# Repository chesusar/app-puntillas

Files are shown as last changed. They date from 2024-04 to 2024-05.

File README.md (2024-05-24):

<div align="Center">
  <h1>Dispositivo IoT de Monitoreo de Equilibrio y Movimiento</h1>
  <p float="left">
    
    
  </p>
</div>

## Descripción
Este proyecto consiste en un dispositivo IoT diseñado para monitorear y analizar el equilibrio y los movimientos relacionados con mantenerse de puntillas. Utiliza un sensor IMU (Unidad de Medición Inercial) y un microcontrolador con Bluetooth para calcular diversas caracteristicas y enviar los datos a una aplicación de PC.

## Características
- **Tiempo hasta el ángulo máximo:** Mide el tiempo que se tarda en alcanzar el ángulo máximo al ponerse de puntillas desde el inicio del movimiento.
- **Tiempo de permanencia en puntillas:** Registra el tiempo durante el cual una persona puede mantenerse de puntillas.
- **Ángulo máximo alcanzado:** Mide el ángulo máximo logrado al estar de puntillas.
- **Ángulo mínimo en puntillas:** Determina el ángulo mínimo mientras se mantiene la posición de puntillas.
- **Promedio del ángulo en puntillas:** Calcula el promedio del ángulo durante la permanencia en puntillas.

## Componentes del Proyecto
- **Hardware del dispositivo IoT:**
  - Sensor IMU
  - Convertidor DC-DC
  - Microcontrolador con Bluetooth
  - Batería y componentes de montaje
- **Software:**
  - Código para el microcontrolador del dispositivo IoT
  - Código para el microcontrolador del recceptor
  - Aplicación para PC

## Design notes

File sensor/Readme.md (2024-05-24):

<div align="Center">
  <h1 align="Center">Dispositivo IoT de Monitoreo de Equilibrio y Movimiento - Sensor</h1>
  <p float="left">
    
  </p>
</div>

## Descripción
Este proyecto utiliza un dispositivo IoT basado en el sensor IMU para monitorear y analizar el equilibrio y los movimientos relacionados con mantenerse de puntillas. El dispositivo emplea un Arduino Nano 33 BLE Sense para procesar los datos del acelerómetro y el giroscopio, aplicando un filtro de Kalman para mejorar la precisión de las mediciones.

## Estructura de Carpetas
- codigo
  - dispositivo_iot.ino

- componentes
  - comparacion_IMUs.pdf
  - comparacion_DCDC.pdf
  - decisiones.pdf

- medidas
  - Datos_arduino
  - Datos_finales
  - Manejo_datos
    - convertir_datos.py
    - representar_datos.m

- modelo_3D
   - carcasa.stl

## Código
### Ubicación
El código fuente del dispositivo IoT se encuentra en la carpeta `codigo`.

### Descripción
El código está desarrollado para el **Arduino Nano 33 BLE Sense** y se encarga de:
- Tomar mediciones del acelerómetro y el giroscopio.
- Aplicar un filtro de Kalman para calcular el ángulo con mayor precisión.
- Enviar los datos procesados vía Bluetooth al receptor bluetooh del PC.

### Filtro de Kalman
El filtro de Kalman se utiliza para combinar las lecturas del acelerómetro y el giroscopio, proporcionando estimaciones más precisas del ángulo, reduciendo el ruido y mejorando la estabilidad de las mediciones.

<center>
  <video src="https://github.com/chesusar/app-puntillas/assets/133507131/c614b8c2-d482-485f-80f9-662d0921a47c" width="226" height="416"/> 
</center>

## Componentes
### Ubicación
La información sobre los componentes se encuentra en la carpeta `componentes`.

### Descripción
- **Sensor inercial.xlsx:** Comparación de diferentes sensores IMU considerados para el proyecto.
- **Reguladores de tensión.xlsx:** Comparación de diferentes convertidores DC-DC utilizados.
- **Comparacion_componentes.pdf:** Documento explicando las decisiones tomadas en la selección de componentes.

## Medidas
### Ubicación
Los datos de las mediciones se encuentran en la carpeta `medidas`.

### Descripción
- **Datos_arduino:** Lecturas de acelerómetro y giroscopio realizadas con el dispositivo IoT en diferentes personas.
- **Datos_finales:** Datos procesados a partir de las lecturas originales, separados en archivos CSV y un archivo Excel con información resumida de cada persona.
- **Manejo_datos:** Scripts para manejar y representar los datos:
  - `convertir_datos.py:` Script en Python para convertir los datos de `Datos_arduino` en `Datos_finales`.
  - `representar_datos.m:` Script en Matlab para representar los datos en gráficos.

## Modelo 3D
### Ubicación
El diseño de la carcasa para el dispositivo se encuentra en la carpeta `modelo_3D`.

### Descripción
- **Tobillera.stl:** Modelo 3D de la carcasa diseñada para integrar la batería y el sensor en un solo dispositivo compacto.

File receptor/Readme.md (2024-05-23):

<div align="Center">
  <h1 align="Center">Receptor Bluetooth con ESP32</h1>
  
</div>

Este proyecto utiliza un ESP32 como receptor Bluetooth para recibir datos de un dispositivo IoT basado en Arduino Nano 33 BLE Sense. El código principal se encuentra en `receptor.ino`.

## Descripción

El código realiza las siguientes tareas:

- Inicializa el módulo Bluetooth del ESP32.
- Publicita el ESP32 como un dispositivo Bluetooth accesible.
- Escanea y se conecta al dispositivo IoT específico.
- Suscribe las características relevantes del servicio Bluetooth.
- Lee y muestra los datos recibidos del dispositivo IoT, tales como ángulos y tiempos.

## Características BLE

El código se conecta a un servicio Bluetooth específico y se suscribe a las siguientes características:

- **UUID_PROCESAR:** Característica para iniciar o detener el procesamiento de datos.
- **UUID_MAX_ANGULO:** Característica que transmite el ángulo máximo medido.
- **UUID_MIN_ANGULO:** Característica que transmite el ángulo mínimo medido.
- **UUID_ANGULO:** Característica que transmite el ángulo actual.
- **UUID_ESTADO:** Característica que transmite el estado actual del dispositivo.
- **UUID_TIEMPO_SUBIDA:** Característica que transmite el tiempo de subida.
- **UUID_TIEMPO_ALTO:** Característica que transmite el tiempo mantenido en la posición elevada.
- **UUID_PROMEDIO:** Característica que transmite el ángulo promedio.

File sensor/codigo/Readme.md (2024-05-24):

<div align="Center">
  <h1 align="Center">Codigo del dispositivo IoT</h1>
  
</div>

## Descripción
Este código realiza las siguientes tareas:

- Inicializa los sensores del Arduino Nano 33 BLE Sense.
- Lee los datos del acelerómetro y el giroscopio.
- Aplica un filtro de Kalman para calcular el ángulo con precisión.
- Monitorea el estado del equilibrio y el movimiento.
- Envía los datos calculados a través de Bluetooth a una aplicación móvil o PC.

## Filtro de Kalman
El filtro de Kalman se utiliza para fusionar las lecturas del acelerómetro y el giroscopio, proporcionando estimaciones más precisas del ángulo y reduciendo el ruido en las mediciones.

<center>
  <h1>Dispositivo IoT de Monitoreo de Equilibrio y Movimiento</h1>
  
  <video src="https://github.com/chesusar/app-puntillas/assets/133507131/c614b8c2-d482-485f-80f9-662d0921a47c" width="226" height="416"/> 
</center>

## Maquina de estados
<div align="Center">
  <p float="left">
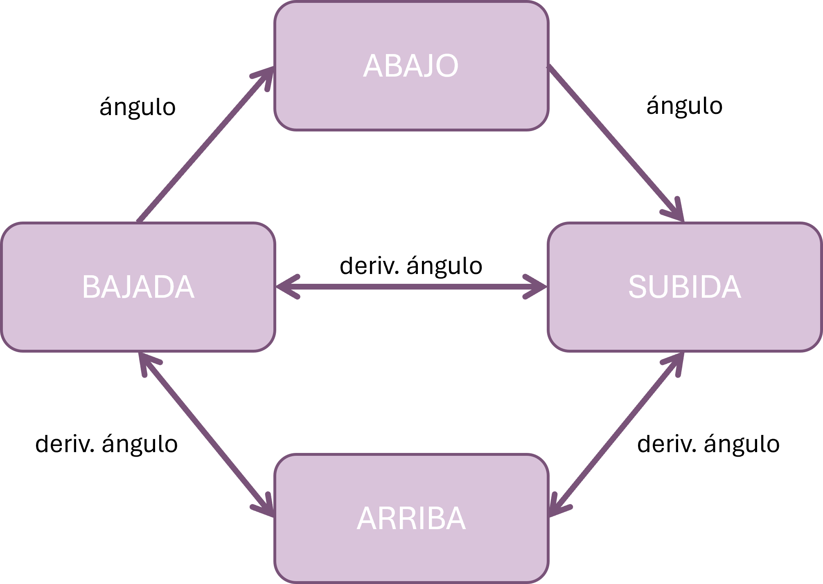
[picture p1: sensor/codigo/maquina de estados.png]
    
  </p>
</div>

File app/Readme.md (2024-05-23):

<div align="Center">
  <h1 align="Center">Na Punta Dos Pes APP</h1>
  <p float="left">
      
    
  </p>
</div>

## Descripción

Esta aplicación en Python se utiliza para interactuar con un dispositivo IoT que envía datos a través de Bluetooth Low Energy (BLE). El código principal se encuentra en `app.py`. La aplicación realiza las siguientes tareas:

- Se conecta al dispositivo IoT a través del receptor BLE.
- Suscribe las características relevantes del servicio BLE.
- Muestra los datos recibidos en una interfaz gráfica de usuario (GUI).
- Almacena los datos recibidos en el servidor de adafruit-io mediante peticiones MQTT.
- Permite iniciar y detener la transmisión de datos desde el dispositivo IoT.

## Datos recibidos y almacenados
- **Tiempo hasta el ángulo máximo:** Mide el tiempo que se tarda en alcanzar el ángulo máximo al ponerse de puntillas desde el inicio del movimiento.
- **Tiempo de permanencia en puntillas:** Registra el tiempo durante el cual una persona puede mantenerse de puntillas.
- **Ángulo máximo alcanzado:** Mide el ángulo máximo logrado al estar de puntillas.
- **Ángulo mínimo en puntillas:** Determina el ángulo mínimo mientras se mantiene la posición de puntillas.
- **Promedio del ángulo en puntillas:** Calcula el promedio del ángulo durante la permanencia en puntillas.

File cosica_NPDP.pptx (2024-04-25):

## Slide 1

Na ponta dos pés
(NPDP)
Sensor IoT puntillas

El proyecto se basa en desarrollar un dispositivo IoT que monitorea el equilibrio y los movimientos de puntillas. El dispositivo integra un sensor IMU y un microcontrolador con Bluetooth, colocándose en el pie derecho de una persona. El objetivo es calcular y registrar el tiempo para alcanzar el ángulo máximo al ponerse de puntillas, el tiempo que permanece en puntillas, el ángulo máximo alcanzado, el ángulo mínimo durante la permanencia en puntillas y el promedio del ángulo mientras se está de puntillas. Este enfoque ofrece aplicaciones potenciales en rehabilitación física, rendimiento deportivo y evaluación biomecánica.

(Arribas R. y Álvarez J., 2024)

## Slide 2

Mapa redondo simplificado e iconos

REAL - MUNDO VIRTUAL INTERFAZ
Interfaz de usuario (App)

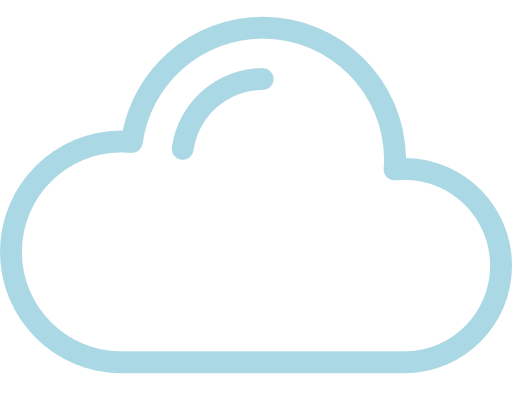
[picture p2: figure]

NUBE

ENTRADAS

Medidas

ENTRADA MANUAL

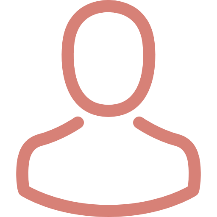
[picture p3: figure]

DEPORTE

SALUD

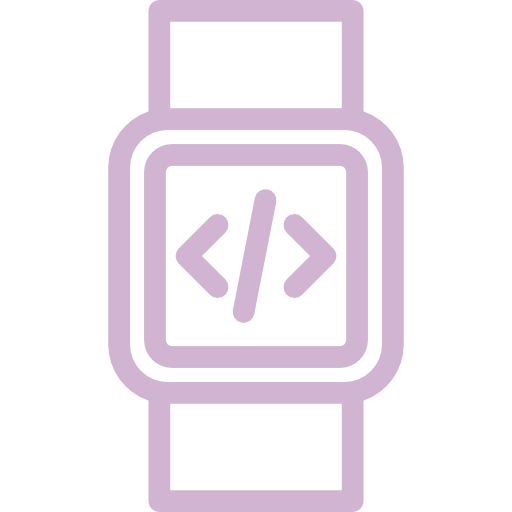
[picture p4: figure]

ENTRADA DE SENSOR

Inicio
Reset

MEDIDAS

Acelerómetro
Giróscopo

ORDENES
Al NPDP

NPDP

Wearable
Medida movimiento

SALIDAS

ENTRADA A LA NUBE

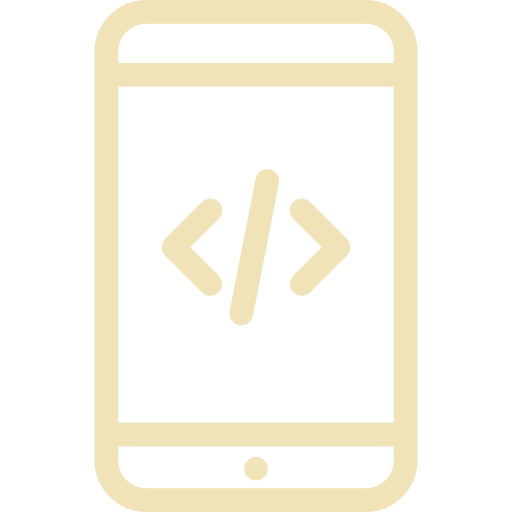
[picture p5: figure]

APP

INTERFAZ DE SALIDA

PC Configuración Visualization

SALIDA DE LA NUBE

APP – NPDP INTERFAZ
Bluetooth

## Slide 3

Entrada de información de los componentes e información generada

Información del mundo | | NPDP | APP | NUBE
Mundo real: Usuario | Medidas de movimiento
| Orden de inicio y de reset
Mundo real: contexto
Mundo virtual

INFORMACIÓN DEDUCIDA | NPDP | APP | NUBE
Tiempo de subida
Tiempo de puntillas
Ángulos

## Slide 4

Razonamiento de lsistema y salida de información generada

RAZONAMIENTO A PARTIR DE INFORMACIÓN COMPARTIDA | TOMA DE DECISIONES AL MUNDO | NPDP | APP | NUBE
Se mide y se notifica al usuario a través de la APP el estado en el que se encuentra, el tiempo que tarda en subir, el tiempo que esta de puntillas, el ángulo máximo, el ángulo mínimo estando de puntillas y el Angulo promedio estando de puntillas
| Notificación al usuario
| Orden de inicio

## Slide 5

Diseño en bloques del dispositivo (NPDP)

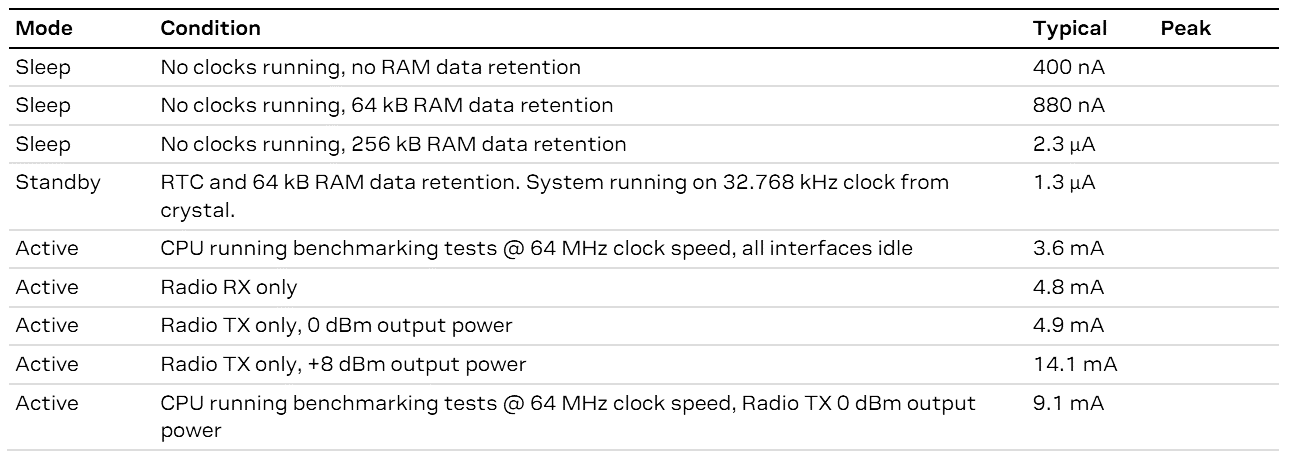
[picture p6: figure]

INTELIGENCIA
- Consta de un algoritmo para la detección del movimiento del pie, basado en las mediciones proporcionadas por el giróscopo y el acelerómetro.

Sensor
- Acelerómetro
- Giróscopo

FUENTE DE ENRGIA

INTELIGENCIA

COMUNICACIÓN

PARTE FISICA

SENSOR

ACTUADOR

WEARABLE

Estructura de la parte física
- Estuctura diseñada para producir en una impresora 3D . Tiene capacidad para almacenar una bateria Li-po. Ademas, de poder albergar el dispositivo IoT

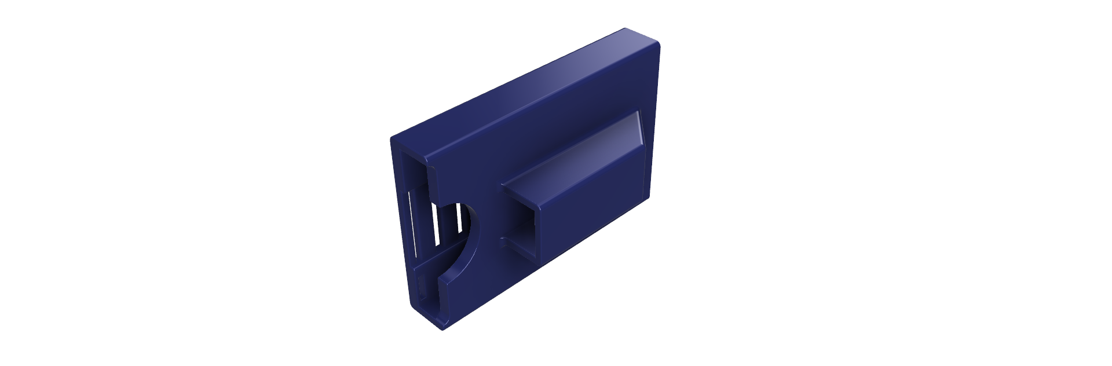
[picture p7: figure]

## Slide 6

Diseño en bloques del dispositivo (APP)

COMUNICACION

INTELIGENCIA

INTERFAZ HUMANA

PARTE FISICA

Interfaz humana
Dispone de 2 pulsadores capaces de iniciar la toma de medidas y resetear los valores almacenados

APP

Parte física

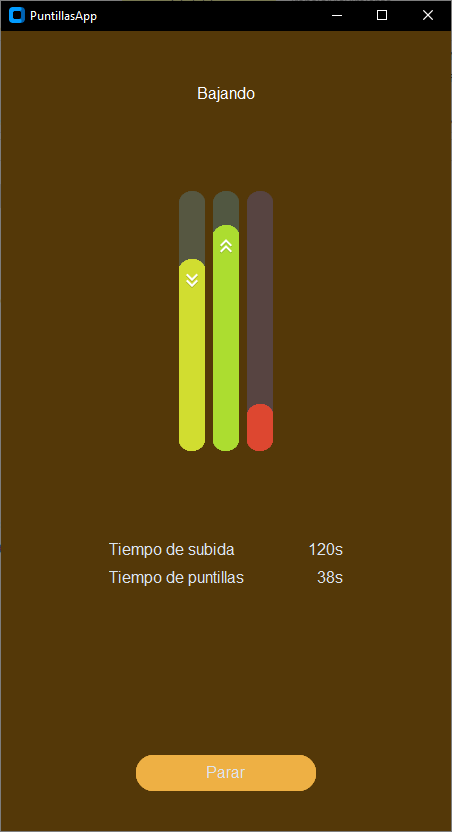
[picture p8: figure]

Inteligencia
Muestra los datos en tiempo real según se recibes desde el NPDP

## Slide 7

Boceto de componentes| Comunicaciones

QUIEN | QUE | CUANDO | COMO
NPDP – APP | Mediciones y cálculos | Una vez este iniciado el sistema cuando haya un dato disponible | Bluetooth
APP - NPDP | Ordenes de inicio y reset | Cuando el usuario oprima los pulsadores de inicio y reset | Bluetooth

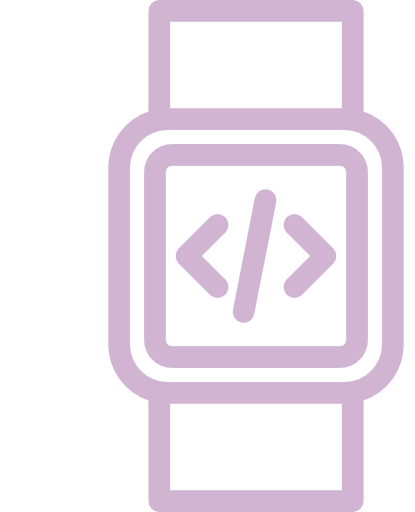
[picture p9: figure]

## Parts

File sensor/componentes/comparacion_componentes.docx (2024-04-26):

# Elección de componentes

# 1 Sensor inercial (IMU)

Se parte del sensor LSM9DS1, el cual presenta una configuración de 9 ejes: 3 para el acelerómetro, 3 para el giróscopo y 3 para el magnetómetro. Aunque este sensor es funcional, se identifica un margen significativo para mejoras. La meta es seleccionar un sensor con 6 ejes, reduciendo así su consumo energético. Además, se persigue mejorar la precisión y la resolución sin comprometer sustancialmente el consumo energético. Este enfoque busca optimizar la eficiencia del dispositivo, garantizando un rendimiento superior en términos de funcionalidad y consumo de energía.

Tabla 1 - Primera comparación de los sensores IMU

| | Acelerómetro | | | | | Consumo
| Nº de ejes | 2g (mg/LSB) | 4g (mg/LSB) | 6g (mg/LSB) | 16g (mg/LSB) | Resolución de salida (bits) | Vin (V) | Iin (mA)
LSM9DS1 | 9 | 0,061 | 0,122 | 0,244 | 0,732 | 16 | 1,9-3,6 | 1,9
ADIS16505-3BMLZ | 6 | 0,061 | 0,122 | 0,244 | 0,488 | 16 | 1,7-3,6 | 0,361
ASM330LHHTR | 6 | 0,061 | 0,122 | 0,244 | 0,488 | 32 | 2-3,6 | 0,36
BHI360 | 6 | 0,061 | 0,122 | 0,244 | 0,488 | 16 | 1,7-3,6 | 3
BMI085 | 6 | 0,061 | 0,122 | 0,244 | 0,488 | 16 | 2,4-3,6 | 5,15
BMI270 | 6 | 0,061 | 0,122 | 0,244 | 0,488 | 16 | 1,2-3,6 | 0,685
IAM-20680HP | 6 | 0,061 | 0,122 | 0,244 | 0,488 | 16 | 1,7-3,6 | 3
ICM-20600 | 6 | 0,061 | 0,122 | 0,244 | 0,488 | 16 | 1,7-3,45 | 2,79
ICM-20602 | 6 | 0,061 | 0,122 | 0,244 | 0,488 | 16 | 1,7-3,6 | 2,79
ICM-40627 | 6 | 0,061 | 0,122 | 0,244 | 0,488 | 16 | 1,7-3,6 | 0,65
ICM-42670-P | 6 | 0,061 | 0,122 | 0,244 | 0,488 | 16 | 1,7-3,6 | 0,55
ICM-42688-V | 6 | 0,061 | 0,122 | 0,244 | 0,488 | 18 | 1,7-3,6 | 0,881
IIM-42652 | 6 | 0,061 | 0,122 | 0,244 | 0,488 | 16 | 1,7-3,6 | 0,67
ISM330DHCXTR | 6 | 0,061 | 0,122 | 0,244 | 0,488 | 16 | 1,7-3,6 | 0,361
ISM330DLCTR | 6 | 0,061 | 0,122 | 0,244 | 0,488 | 16 | 1,7-3,6 | 0,75
LSM6DS3TR-C | 6 | 0,061 | 0,122 | 0,244 | 0,488 | 16 | 1,7-3,6 | 0,16
LSM6DSLTR | 6 | 0,061 | 0,122 | 0,244 | 0,488 | 16 | 1,7-3,6 | 0,65
LSM6DSOTR | 6 | 0,061 | 0,122 | 0,244 | 0,488 | 16 | 1,7-3,6 | 0,55
LSM6DSRTR | 6 | 0,061 | 0,122 | 0,244 | 0,488 | 16 | 1,7-3,6 | 0,36
MPU-6500 | 6 | 0,061 | 0,122 | 0,244 | 0,488 | 16 | 1,7-3,45 | 3,4

Tabla 2 - Segunda comparación de sensores IMU

| Giróscopo
| 125 grados/s (miligrados/s/LSB) | 250 grados/s (miligrados/s/LSB) | 500 grados/s (miligrados/s/LSB) | 1000 grados/s (miligrados/s/LSB) | 2000 grados/s (miligrados/s/LSB)
LSM9DS1 | - | 8,75 | 17,5 | - | 70
ADIS16505-3BMLZ | 4,375 | 8,75 | 17,5 | 35 | 70
ASM330LHHTR | 4,37 | 8,75 | 17,5 | 35 | 70
BHI360 | 3,815 | 7,629 | 15,259 | 30,518 | 61,035
BMI085 | 3,815 | 7,629 | 15,259 | 30,518 | 61,035
BMI270 | 3,815 | 7,629 | 15,259 | 30,518 | 61,035
IAM-20680HP | - | 7,634 | 15,267 | 30,488 | 60,976
ICM-20600 | - | 7,634 | 15,267 | 30,488 | 60,976
ICM-20602 | - | 7,634 | 15,267 | 30,488 | 60,976
ICM-40627 | 3,817 | 7,634 | 15,267 | 30,488 | 60,976
ICM-42670-P | - | 7,634 | 15,267 | 30,488 | 60,976
ICM-42688-V | 3,817 | 7,634 | 15,267 | 30,488 | 60,976
IIM-42652 | 3,817 | 7,634 | 15,267 | 30,488 | 60,976
ISM330DHCXTR | 4,375 | 8,75 | 17,5 | 35 | 70
ISM330DLCTR | 4,375 | 8,75 | 17,5 | 35 | 70
LSM6DS3TR-C | 4,375 | 8,75 | 17,5 | 35 | 70
LSM6DSLTR | 4,375 | 8,75 | 17,5 | 35 | 70
LSM6DSOTR | 4,375 | 8,75 | 17,5 | 35 | 70
LSM6DSRTR | 4,375 | 8,75 | 17,5 | 35 | 70
MPU-6500 | - | 7,634 | 15,267 | 30,488 | 60,976

Para seleccionar el sensor mas optimo para nuestra implementación se ha seguido el criterio de la Tabla 3.

Tabla 3 - Criterio de comparación de sensores IMU

Consumo elevado
Hay otro con la misma precisión con menor consumo
Hay otro con más precisión
Destaca en algo
Mas optimo

Como se puede ver en la Tabla 1 todos los dispositivos estudiados mejoran en precisión al sensor de referencia. Además, se puede ver como 2 sensores destacan por tener una mayor resolución. Finalmente se ha optado por implementar un sensor con una resolución de 16 bits ya que los miligrado/s obtenidos son suficientes para la implementación que se está desarrollando además de disponer de un menor consumo.

En el caso de la Tabla 2 se aprecia que hay sensores con mejores precisiones en un mayor rango de trabajo que el sensor de referencia. Se ha acabado optando por el sensor LSM6DS3TR-C este mejora la precisión del acelerómetro y el rango de trabajo del giróscopo reduciendo considerablemente el consumo energético.

# 2 Regulador de tensión DC-DC

El dispositivo IoT debe contar con el microcontrolador nina b306 este dispone de varios modos de funcionamiento como se muestra en la Tabla 4. Este trabajará en dos modos en Standby mientras se encuentra en reposo, con un consumo de 1,3 µA, y en estado activo con Radio TX + 8 dBm output power, esto es debido a la comunicación bluetooth implementada con un consumo de 14,1 mA.

Tabla 4 - consumo del microcontrolador nina b306

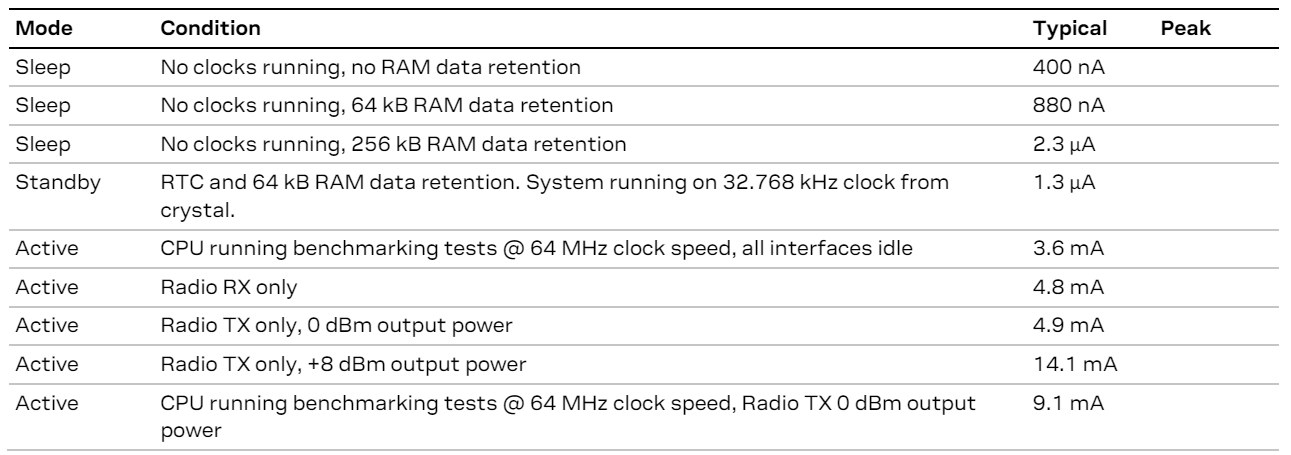
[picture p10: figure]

También hay que tener en cuenta el consumo del sensor IMU siendo de 160 µA. En la Ecuación 1 y Ecuación 2 se muestra el consumo del dispositivo IoT en función del estado de trabajo.

Ecuación 1 - Consumo del dispositivo IoT comunicando por bluetooth

Consumo=14,1+0,16=14,26 mA

Ecuación 2 - Consumo del dispositivo IoT en standby

Consumo=1,3+160=161,3 µA

Se quiere implementar un regulador conmutado el cual sea lo mas eficiente posible en ambos estados de funcionamiento.

Tabla 5 - Comparación de reguladores dc-dc conmutados

| Vin (V) | Vout (V) | Iout (A) | Consumo en reposo (uA) | Frecuencia de conmutación (kHz) | Topología | Eficiencia BLE on (%) | Eficiencia standby (%)
A81805KESJSR | 3,5-36 | 3,3 | 2,5 | 6 | 400-2500 | Buck | > 70 | > 60
ADP2107ACPZ-3.3-R7 | 2,7-5,5 | 3,3 | 2 | 20 | 1200 | Buck-boost | > 72 | > 50
LM536013QDSXRQ1 | 3,55-36 | 3,3 | 1 | 23 | 2100 | Buck | > 60 | -
LM536013QUDSXRQ1 | 3,55-36 | 3,3 | 1 | 6,5 | 2100 | Buck | > 60 | -
LM536023QPWPTQ1 | 3,55-36 | 3,3 | 2 | 8 | 2100 | Buck | > 90 | > 55
LM63635CA3QDRRRQ1 | 3,5-36 | 3,3 | 3,25 | 23 | 400 | Buck | > 90 | > 85
LM63635CC3QDRRRQ1 | 2,7-36 | 3,3 | 3,25 | 23 | 2100 | Buck-boost | > 87 | > 80

Tabla 6- Criterio de comparación de reguladores dc-dc

Baja eficiencia
Otro con mayor eficiencia
Destaca en algo

Se ha optado por implementar el regulador LM63635CA3QDRRRQ1, el cual obtiene el mejor ratio de eficiencia en ambos estados con el menor consumo posible.

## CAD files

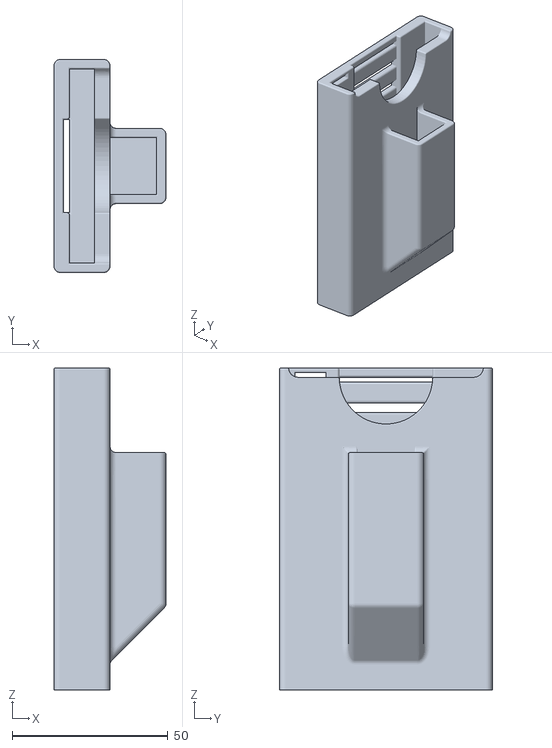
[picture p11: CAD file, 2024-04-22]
sensor/modelo_3D/Tobillera.stl
36.0 x 68.5 x 103.5

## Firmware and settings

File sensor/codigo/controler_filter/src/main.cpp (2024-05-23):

#include <Arduino.h>
#include <Arduino_LSM9DS1.h>
#include <ArduinoBLE.h>
#include "vector3.h"
#include "kalman.h"

#define SAMPLE_MS 50

// Umbrales transición de estados
const float ANGLE_THRESHOLD = 2;
const float DERIV_ANGLE_THRESHOLD = 20;

// Estados
const int ST_ABAJO = 1;
const int ST_SUBIDA = 2;
const int ST_ARRIBA = 3;
const int ST_BAJADA = 4;
int state = ST_ABAJO;
const String STATE_STRING[5] = {"EMPTY", "ABAJO", "SUBIDA", "ARRIBA", "BAJADA"};

kalman filtroY(SAMPLE_MS / 1000.0);

// Bluetooth
BLEService movService("6282a2a1-5f99-430e-abda-ba09b255bdd4");

BLECharCharacteristic procesoChar("99ee8226-8c9e-4972-b4f5-ea7af1caa0b5", BLEWrite);
BLEDescriptor procesoDes("0x2901", "Empezar proceso");
BLECharCharacteristic resetChar("7b14e65a-8610-4cd5-8653-5a3e0020204e", BLEWrite);
BLEDescriptor resetDes("0x2901", "Reset");

BLEIntCharacteristic maxChar("17cc3d4f-69c7-4e00-a954-0346ecbb22c7", BLERead | BLENotify);
BLEDescriptor maxDes("0x2901", "Angulo maximo");
BLEIntCharacteristic minChar("6a8adb71-4b3b-421f-b5e1-e74bad969122", BLERead | BLENotify);
BLEDescriptor minDes("0x2901", "Angulo minimo");
BLEIntCharacteristic medioChar("fdee3592-43f5-40ac-b408-2a15a0b4413c", BLERead | BLENotify);
BLEDescriptor medioDes("0x2901", "Angulo medio");
BLECharCharacteristic subidaChar("64247fd3-2d0e-461f-ac13-8651d2ba991e", BLERead | BLENotify);
BLEDescriptor subidaDes("0x2901", "Tiempo de subida");
BLECharCharacteristic altoChar("ddc902e8-9d9f-4db6-ba57-76609f6d2adb", BLERead | BLENotify);
BLEDescriptor altoDes("0x2901", "Tiempo en alto");

BLEIntCharacteristic anguloChar("38b48b19-373f-4425-a790-42df14c08300", BLERead | BLENotify);
BLEIntCharacteristic estadoChar("c4346fa0-d0ee-4c24-817f-0fab75a7fd23", BLERead | BLENotify);

void process();
float processAngle();
Vector3 getLastAcceleration();
Vector3 getLastAngularVelocity();

void iniciarBLE();

void setup()
{
  Serial.begin(115200);
  if (!IMU.begin())
  {
    Serial.println("Failed to initialize IMU!");
  }

  iniciarBLE();
}

void loop()
{
  uint32_t startMillis = millis();

  static BLEDevice central = BLE.central();
  int resetear = 0;
  static uint8_t procesando = 0;
  static int debug_conectado = 0;

  if (central)
  {
    if (debug_conectado == 0)
    {
      debug_conectado = 1;
      Serial.println("Conexion entrante");
    }
    if (central.connected())
    {
      if (procesoChar.written())
      {
        procesando = procesoChar.value();
        Serial.print("Proceso recibido ");
        Serial.println(procesando);
      }
      if (resetChar.written())
      {
        resetear = resetChar.value();
        resetChar.writeValue(0);
        Serial.println("Reset recibido");
        if (resetear == 1)
        {
          state = ST_ABAJO;
        }
      }
    }
  }
  else
  {
    if (debug_conectado == 1)
    {
      debug_conectado = 0;
      Serial.println("Conexion cerrada");
    }
    central = BLE.central();
  }

  if (procesando == 1)
  {
    process();
  }

  uint32_t elapsedTime = millis() - startMillis;
  uint32_t delayTime = SAMPLE_MS - elapsedTime;
  delayTime = delayTime > 0 ? delayTime : 0;
  delay(delayTime);
}

void process()
{
  // Tiempos
  static int tiempoSubida = 0;
  static int tiempoArriba = 0;

  // Angulos
  static float angle = 0.0;
  static float angleRaw = 0.0;
  static float angleOffset = 0.0;
  float angleAnterior = angle;
  float angleDeriv;
  static int anguloMaximo = 0;
  static int anguloMinimo = 999;
  static int anguloPromedio = 0;
  static int anguloPromedioContador = 0;

  angleRaw = processAngle();
  angle = angleRaw - angleOffset;
  angleDeriv = (angle - angleAnterior) / (SAMPLE_MS / 1000.0);

  anguloChar.writeValue((int)angle);

  switch (state)
  {
  case ST_ABAJO:
    tiempoArriba = 0;
    tiempoSubida = 0;
    anguloMaximo = 0;
    anguloMinimo = 999;
    anguloPromedio = 0;
    anguloPromedioContador = 0;

    if (angle >= ANGLE_THRESHOLD)
    {
      state = ST_SUBIDA;
      estadoChar.writeValue((int)state);
    }
    break;

  case ST_SUBIDA:
    tiempoSubida += SAMPLE_MS;
    anguloPromedio += angle;
    anguloPromedioContador += 1;

    if (angle > anguloMaximo)
    {
      anguloMaximo = angle;
    }

    if (angleDeriv < -DERIV_ANGLE_THRESHOLD)
    {
      state = ST_BAJADA;
      estadoChar.writeValue((int)state);
    }
    else if (angleDeriv < DERIV_ANGLE_THRESHOLD)
    {
      state = ST_ARRIBA;
      estadoChar.writeValue((int)state);
    }
    break;

  case ST_ARRIBA:
    tiempoArriba += SAMPLE_MS;
    anguloPromedio += angle;
    anguloPromedioContador += 1;
    if (angle > anguloMaximo)
    {
      anguloMaximo = angle;
    }
    if (angle < anguloMinimo)
    {
      anguloMinimo = angle;
    }

    if (angleDeriv > DERIV_ANGLE_THRESHOLD)
    {
      state = ST_SUBIDA;
      estadoChar.writeValue((int)state);
    }
    else if (angleDeriv < -DERIV_ANGLE_THRESHOLD)
    {
      state = ST_BAJADA;
      estadoChar.writeValue((int)state);
    }
    if (angle <= ANGLE_THRESHOLD)
    {
      state = ST_ABAJO;
      estadoChar.writeValue((int)state);
      minChar.writeValue((int)anguloMinimo);
      maxChar.writeValue((int)anguloMaximo);
      subidaChar.writeValue((int)tiempoSubida / 100);
      altoChar.writeValue((int)tiempoArriba / 100);
      medioChar.writeValue((int)anguloPromedio / anguloPromedioContador);
    }
    break;

  case ST_BAJADA:
    anguloPromedio += angle;
    anguloPromedioContador += 1;
    if (angleDeriv > DERIV_ANGLE_THRESHOLD)
    {
      state = ST_SUBIDA;
      estadoChar.writeValue((int)state);
    }
    else if (angleDeriv > -DERIV_ANGLE_THRESHOLD)
    {
      state = ST_ARRIBA;
      estadoChar.writeValue((int)state);
    }
    if (angle <= ANGLE_THRESHOLD)
    {
      state = ST_ABAJO;
      estadoChar.writeValue((int)state);
      minChar.writeValue((int)anguloMinimo);
      maxChar.writeValue((int)anguloMaximo);
      subidaChar.writeValue((int)tiempoSubida / 100);
      altoChar.writeValue((int)tiempoArriba / 100);
      medioChar.writeValue((int)anguloPromedio / anguloPromedioContador);
    }
    break;

  default:
    break;
  }

  // Serial.print(angle);
  // Serial.print("\t");
  // Serial.print(angleDeriv);
  // Serial.print("\t");
  // Serial.print(STATE_STRING[state]);
  // Serial.print("\t");
  // Serial.print(tiempoSubida);
  // Serial.print("\t");
  // Serial.println(tiempoArriba);
}

float processAngle()
{
  static float angleAccel = 0.0;

  // Acceleration
  Vector3 accel = getLastAcceleration();
  // Invertir vector g
  accel.x = -accel.x;
  accel.y = -accel.y;
  accel.z = -accel.z;
  if (accel.x != 0.0) // Evitar propagación de Nan
  {
    angleAccel = accel.getAngleY() - 90.0; // Ángulo 0 cuando en reposo
  }

  // Gyroscope
  Vector3 velocity = getLastAngularVelocity();

  float angleKalman = filtroY.process(-velocity.y, angleAccel);

  return angleKalman;
}

Vector3 getLastAcceleration()
{
  static float aX, aY, aZ;
  Vector3 v(-aX, -aZ, aY);
  if (IMU.accelerationAvailable())
  {
    IMU.readAcceleration(aX, aY, aZ);
    v.x = -aX;
    v.y = -aZ;
    v.z = aY;
  }
  return v;
}

Vector3 getLastAngularVelocity()
{
  static float aX, aY, aZ;
  Vector3 v(aX, aZ, -aY);
  if (IMU.gyroscopeAvailable())
  {
    IMU.readGyroscope(aX, aY, aZ);
    v.x = aX;
    v.y = aZ;
    v.z = -aY;
  }
  return v;
}

void iniciarBLE()
{
  if (!BLE.begin())
  {
    Serial.println("starting Bluetooth® Low Energy failed!");
  }
  BLE.setLocalName("DispositivoDoCaminaçao");

  BLE.setAdvertisedService(movService);

  subidaChar.addDescriptor(subidaDes);
  movService.addCharacteristic(subidaChar);

  altoChar.addDescriptor(altoDes);
  movService.addCharacteristic(altoChar);

  medioChar.addDescriptor(medioDes);
  movService.addCharacteristic(medioChar);

  minChar.addDescriptor(minDes);
  movService.addCharacteristic(minChar);

  maxChar.addDescriptor(maxDes);
  movService.addCharacteristic(maxChar);

  resetChar.addDescriptor(resetDes);
  movService.addCharacteristic(resetChar);

  procesoChar.addDescriptor(procesoDes);
  movService.addCharacteristic(procesoChar);

  movService.addCharacteristic(anguloChar);
  movService.addCharacteristic(estadoChar);

  BLE.addService(movService);

  BLE.advertise();
}

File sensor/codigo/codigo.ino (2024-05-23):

#include <ArduinoBLE.h>
#include <Arduino_LSM9DS1.h>

#define T_SAMPLE_MS 50

#define D_ACEL_THRESHOLD 0.3  // Umbral derivada aceleración
#define D_ACEL_THRESHOLD_PARADA 0.15
#define ACEL_THRESHOLD_ABAJO 0.05

// Estados
const int ST_ABAJO = 1;
const int ST_SUBIDA = 2;
const int ST_ARRIBA = 3;
const int ST_BAJADA = 4;
int estado = ST_ABAJO;

// Tiempos
int inicio_subida = 0;
int parada_subida = 0;
int tiempo_subida = 0;
int inicio_puntillas = 0;
int parada_puntillas = 0;
int tiempo_puntillas = 0;

// Medidas angulos
#define ANGULO_OFFSET 20
float angulo = ANGULO_OFFSET;
float angulo_maximo = 0;
float angulo_minimo = 999;
float angulo_promedio = 0;
float suma_angulo = 0;
float cuenta_angulo = 0;

// Buffer medidas. Tamaño de ventana de filtro BUFFER_SIZE
#define BUFFER_SIZE 5
float bufferAcelX[BUFFER_SIZE];

BLEService movService("6282a2a1-5f99-430e-abda-ba09b255bdd4");

BLECharCharacteristic procesoChar("99ee8226-8c9e-4972-b4f5-ea7af1caa0b5", BLEWrite);
BLEDescriptor procesoDes("0x2901", "Empezar proceso");
BLECharCharacteristic resetChar("7b14e65a-8610-4cd5-8653-5a3e0020204e", BLEWrite);
BLEDescriptor resetDes("0x2901", "Reset");

BLEIntCharacteristic maxChar("17cc3d4f-69c7-4e00-a954-0346ecbb22c7", BLERead | BLENotify);
BLEDescriptor maxDes("0x2901", "Angulo maximo");
BLEIntCharacteristic minChar("6a8adb71-4b3b-421f-b5e1-e74bad969122", BLERead | BLENotify);
BLEDescriptor minDes("0x2901", "Angulo minimo");
BLEIntCharacteristic medioChar("fdee3592-43f5-40ac-b408-2a15a0b4413c", BLERead | BLENotify);
BLEDescriptor medioDes("0x2901", "Angulo medio");
BLECharCharacteristic subidaChar("64247fd3-2d0e-461f-ac13-8651d2ba991e", BLERead | BLENotify);
BLEDescriptor subidaDes("0x2901", "Tiempo de subida");
BLECharCharacteristic altoChar("ddc902e8-9d9f-4db6-ba57-76609f6d2adb", BLERead | BLENotify);
BLEDescriptor altoDes("0x2901", "Tiempo en alto");

BLEIntCharacteristic anguloChar("38b48b19-373f-4425-a790-42df14c08300", BLERead | BLENotify);
BLEIntCharacteristic estadoChar("c4346fa0-d0ee-4c24-817f-0fab75a7fd23", BLERead | BLENotify);

void setup() {
  Serial.begin(115200);

  if (!IMU.begin()) {
    Serial.println("Failed to initialize IMU!");
    while (1)
      ;
  }

  // Iniciar buffers a 0
  bufferInit(bufferAcelX, BUFFER_SIZE);

  // BLE
  if (!BLE.begin()) {
    Serial.println("starting Bluetooth® Low Energy failed!");
    while (1)
      ;
  }
  BLE.setLocalName("DispositivoDoCaminaçao");

  BLE.setAdvertisedService(movService);

  subidaChar.addDescriptor(subidaDes);
  movService.addCharacteristic(subidaChar);

  altoChar.addDescriptor(altoDes);
  movService.addCharacteristic(altoChar);

  medioChar.addDescriptor(medioDes);
  movService.addCharacteristic(medioChar);

  minChar.addDescriptor(minDes);
  movService.addCharacteristic(minChar);

  maxChar.addDescriptor(maxDes);
  movService.addCharacteristic(maxChar);

  resetChar.addDescriptor(resetDes);
  movService.addCharacteristic(resetChar);

  procesoChar.addDescriptor(procesoDes);
  movService.addCharacteristic(procesoChar);

  movService.addCharacteristic(anguloChar);
  movService.addCharacteristic(estadoChar);

  BLE.addService(movService);

  BLE.advertise();
}

void loop() {
  static uint8_t procesando = 0;
  static int deltaTimeMs = 0;
  static BLEDevice central = BLE.central();
  int resetear = 0;
  int startTime = millis();

  static int debug_conectado = 0;

  if (central) {
    if (debug_conectado == 0) {
      debug_conectado = 1;
      Serial.println("Conexion entrante");
    }
    if (central.connected()) {
      if (procesoChar.written()) {
        procesando = procesoChar.value();
        Serial.print("Proceso recibido ");
        Serial.println(procesando);
      }
      if (resetChar.written()) {
        resetear = resetChar.value();
        resetChar.writeValue(0);
        Serial.println("Reset recibido");
      }
    }
  } else {
    if (debug_conectado == 1) {
      debug_conectado = 0;
      Serial.println("Conexion cerrada");
    }
    central = BLE.central();
  }


  if (resetear == 1) {
    Serial.println("Entrado en reset");
    angulo = ANGULO_OFFSET;
    angulo_maximo = 0;
    angulo_minimo = 999;
    angulo_promedio = 0;
    suma_angulo = 0;
    cuenta_angulo = 0;
    estado = ST_ABAJO;
    bufferInit(bufferAcelX, BUFFER_SIZE);
    resetear = 0;
  }

  if (procesando == 1) {
    procesado();
  }

  deltaTimeMs = millis() - startTime;

  if (T_SAMPLE_MS - deltaTimeMs >= 0)
    delay(T_SAMPLE_MS - deltaTimeMs);
}

void procesado() {
  float acelX = 0.0, acelY = 0.0, acelZ = 0.0;
  float giroX = 0.0, giroY = 0.0, giroZ = 0.0;

  float acelMeanX = 0.0;
  static float acelMeanXAnt = 0.0;
  float dAcelX = 0.0;

  if (IMU.accelerationAvailable()) {
    float x, y, z;
    IMU.readAcceleration(x, y, z);
    acelX = -x;
    acelY = -z;
    acelZ = y;
    bufferAdd(bufferAcelX, BUFFER_SIZE, acelX);
    // bufferPrint(bufferAcelX, BUFFER_SIZE);
    // Serial.print("Mean ");
    // Serial.println(bufferMean(bufferAcelX, BUFFER_SIZE));
  }

  if (IMU.gyroscopeAvailable()) {
    float x, y, z;
    IMU.readGyroscope(x, y, z);
    giroX = x;
    giroY = z;
    giroZ = -y;
  }

  // Derivada acel
  acelMeanX = bufferMean(bufferAcelX, BUFFER_SIZE);
  dAcelX = (acelMeanX - acelMeanXAnt) / (T_SAMPLE_MS / 1000.0);

  acelMeanXAnt = acelMeanX;

  angulo = angulo - giroY * (T_SAMPLE_MS / 1000.0);  // Eje y giro positivo hacia abajo
  anguloChar.writeValue((int)angulo);
  
  maxChar.writeValue((int)angulo_maximo);

  if (angulo_minimo > 800) {
    Serial.print("Angulo MIN: ");
    Serial.println(angulo);
    minChar.writeValue((int)angulo);
  } else {
    Serial.print("Angulo MIN: ");
    Serial.println(angulo_minimo);
    minChar.writeValue((int)angulo_minimo);
  }

  // Serial.print("angulo: ");
  // Serial.println(angulo);

  if (estado == ST_ABAJO) {
    angulo = ANGULO_OFFSET;

    if (acelX > ACEL_THRESHOLD_ABAJO) {
      Serial.println("Cambio de estado a subiendo");
      inicio_subida = millis();
      estadoChar.writeValue((int)ST_SUBIDA);
      estado = ST_SUBIDA;
    }
  }

  else if (estado == ST_SUBIDA) {
    angulo_maximo = 0;
    angulo_minimo = 999;
    angulo_promedio = 0;
    suma_angulo = 0;
    cuenta_angulo = 0;

    if (dAcelX < D_ACEL_THRESHOLD_PARADA && dAcelX > -D_ACEL_THRESHOLD_PARADA) {
      Serial.println("Cambio de estado a arriba");
      parada_subida = millis();
      tiempo_subida = (parada_subida - inicio_subida)/100;
      Serial.print("Tiempo subida: ");
      Serial.println(tiempo_subida);
      subidaChar.writeValue((int)tiempo_subida);
      estadoChar.writeValue((int)ST_ARRIBA);
      estado = ST_ARRIBA;
    }
  }

  else if (estado == ST_ARRIBA) {
    inicio_puntillas = parada_subida;

    if (angulo_maximo < angulo) {
      angulo_maximo = angulo;
      Serial.print("Angulo MAX: ");
      Serial.println(angulo_maximo);
      // maxChar.writeValue((int)angulo_maximo);
    }
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

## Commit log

2024-04-22 Añadida app para pc
2024-04-22 implementacion sensor
2024-04-23 test
    test
    [Reguladores de tensión.xlsx, Sensor inercial.xlsx]
2024-04-24 maquina de estados
2024-04-26 actualizacion comparacion
    [Reguladores de tensión.xlsx, Sensor inercial.xlsx]
2024-04-28 ajuste de tamaño
2024-04-29 arreglado errores al cerrar la aplicacion
    [app.py]
2024-04-29 mejoras en la aplicación, colores, márgenes, barras
2024-05-01 fluided animacion de barras y formato de texto en tiempos
2024-05-02 crear clase NPDPDevice para manejo del NPDP con independencia del Serial o BLE
2024-05-23 Update Readme.md del sensor
2024-05-23 Update Readme.md de la app
2024-05-23 nuevo proyecto sensor con filtro de kalman
2024-05-24 Update Readme.md de sensor
